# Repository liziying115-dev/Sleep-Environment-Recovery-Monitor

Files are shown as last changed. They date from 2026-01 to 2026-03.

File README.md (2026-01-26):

## Sleep Environment & Recovery Monitor
### Project Overview
#### What it does

The Sleep Environment & Recovery Monitor evaluates overnight sleep conditions — light, sound, temperature — and translates them into a simple, physical recovery score visible in the morning. Instead of tracking the body, the system focuses on environmental quality to encourage healthier sleep habits without medical claims.

#### What it looks like

The system consists of two devices:
* A sensor unit placed on a nightstand that quietly monitors the sleep environment overnight (light, sound, temperature)
* A display unit resembling a small alarm clock with an OLED screen, LED indicator, and a stepper-motor-driven gauge needle that physically points to your sleep quality score

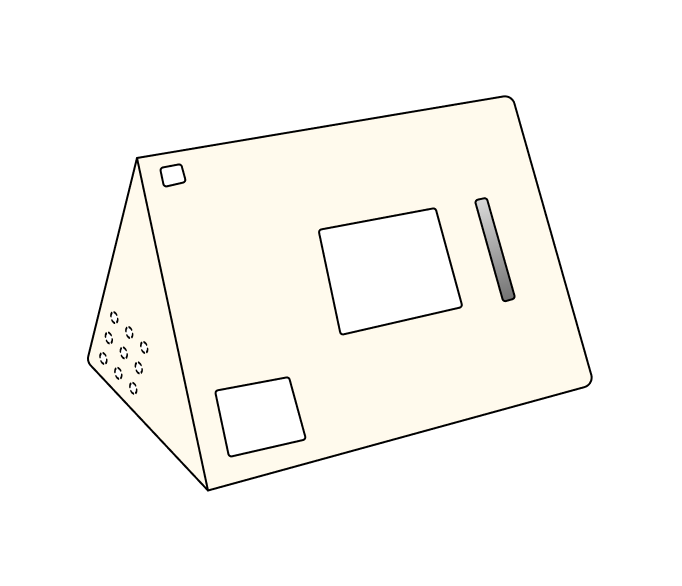
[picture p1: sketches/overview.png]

### Sensor Device (Sleep Environment Monitor)
#### Description
The sensor device continuously monitors environmental conditions during sleep using a low-power duty cycle. Data is aggregated overnight and transmitted wirelessly to the display device in the morning.

#### Sensors & Parts (part numbers)
| Function | Part Number | Quantity | Description |
|---|---|---|---|
| MCU + Wireless| Seeed Studio XIAO ESP32-C3| 1 | BLE, low power |
| Ambient Light Sensor | VEML7700 | 1 | High-sensitivity ambient light sensor (I²C) |
| Microphone | SPH0645LM4H-B | 1 | I²S MEMS microphone, RMS only |
| Temperature | BME280 | 1 | temperature sensing |
| Battery Charger | MCP73831 | 1 | LiPo charging IC |
| LiPo Battery | 3.7V 1000-2000mAh | 1 | Power supply |

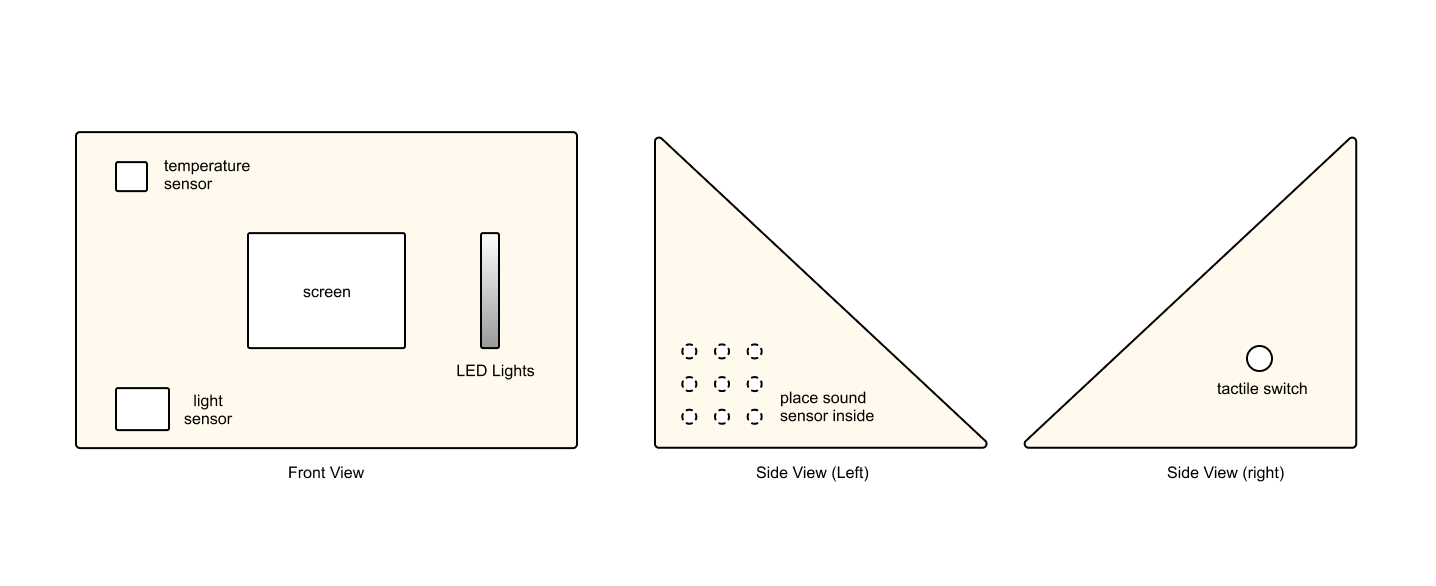
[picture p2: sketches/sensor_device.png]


#### How it works
- The device wakes on a scheduled interval during sleep hours.
- Light, sound RMS, temperature are sampled.
- Audio is processed locally (no recording or storage).
- All data is time-weighted and stored in local memory.
- At wake time, a summary packet is transmitted to the display device.

### Display Device (Score Interface)
#### Description
The display device receives environmental data wirelessly and presents the overnight Sleep Environment Score using multiple feedback channels: a physical gauge needle, OLED screen, and ambient LED indicator. A single button allows the user to cycle through secondary metrics such as light exposure, noise level, and temperature.

#### Components & Parts
| Function | Part Number | Quantity | Notes |
|---|---|---|---|
| MCU + Wireless | Seeed Studio XIAO ESP32-C3 | 1 | Wireless receiver |
| Display | SSD1306 OLED (128×64) | 1 | Low-power I²C screen |
| Stepper Motor | 28BYJ-48 (5V) | 1 | Drives gauge needle |
| Motor Driver  | ULN2003 Driver Board | 1 | Stepper motor driver |
| Gauge Needle  | Custom (3D printed)  | 1 | Physical pointer (0-100) |
| LED | Warm White Diffused LED | 1 | Ambient sleep quality indicator |
| Button | Tactile Momentary Switch | 1 | Metric navigation |
| Battery | LiPo 2000 mAh | 1 | Multi-day operation |
| Resistor | 220Ω | 1 | LED current limiting |

#### Gauge Needle Design

Scale: 0-100 (semi-circular arc)

Zones:
- 0-50: Red zone (Poor)
- 50-70: Orange zone (Fair)
- 70-90: Yellow zone (Good)
- 90-100: Green zone (Excellent)

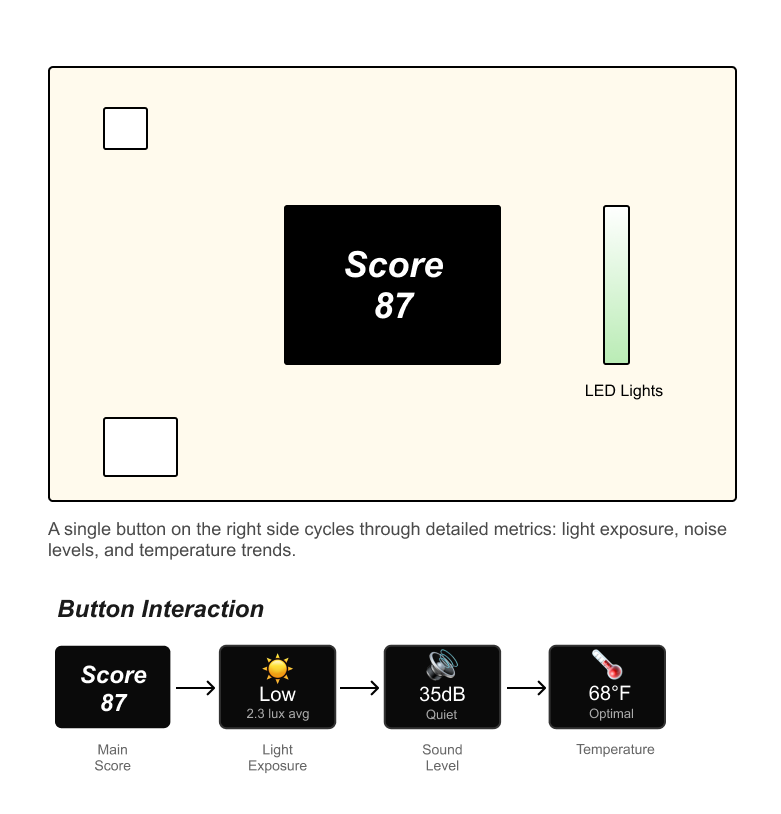
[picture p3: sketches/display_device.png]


### System Communication & Data Flow

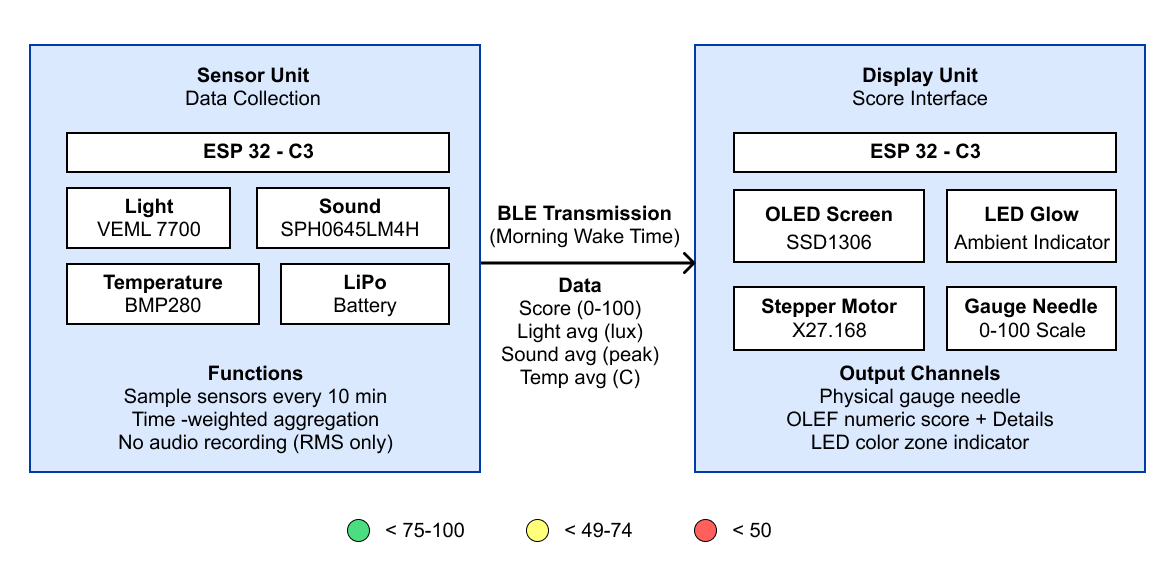
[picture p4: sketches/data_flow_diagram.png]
Data Flow Diagram


*Figure: Complete data pipeline from sensors through processing to display outputs.*

#### System Communication
The system consists of two standalone devices that communicate wirelessly:

Sensor Unit (Transmitter):
- Operates independently overnight
- Collects and aggregates environmental data
- Transmits single summary packet in the morning

Display Unit (Receiver):
- Listens for BLE transmission from sensor unit
- Receives aggregated data and calculated score
- Updates three output channels: gauge needle, OLED, LED

Communication Protocol:
- Technology: BLE
- Pairing: One-time setup, devices remember each other
- Data Format: JSON or binary packet containing:
  - Overall score (0-100)
  - Average light level (lux)
  - Average sound level (dB RMS)
  - Average temperature (°F/°C)
  - Timestamp

#### Data Flow & Processing Pipeline

During Sleep Period:
1. Sensor device periodically samples ambient light, sound level, and temperature
2. Audio data is processed locally using RMS calculation and basic spectral weighting to emphasize disruptive noise patterns
3. All sensor readings are time-weighted (e.g., disruptions during REM sleep weighted higher)
4. Data is aggregated into a single overnight dataset

Morning Transmission:
1. Aggregated data is converted into a normalized Sleep Environment Score (0-100)
2. Score and detailed metrics are packaged into BLE transmission packet
3. Sensor unit broadcasts packet to display unit
4. Display unit receives data and updates all feedback channels

Physical Feedback:
- Gauge Needle: Stepper motor positions needle to corresponding score (0-100 scale)
- OLED Screen: Displays numeric score and allows cycling through detailed metrics
- LED Indicator: Glows with color corresponding to quality zone (green/yellow/orange/red)

### Future Work
- Optional Wi-Fi connectivity to support long-term data logging or remote visualization

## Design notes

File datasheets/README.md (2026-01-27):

## Component Datasheets

This folder contains datasheets for all components used in the Sleep Environment & Recovery Monitor project.

### Sensor Device Components

#### Microcontroller & Wireless
**Seeed Studio XIAO ESP32-C3**
- File: `esp32-c3_datasheet.pdf`
- Description: Low-power MCU with BLE and Wi-Fi capabilities
- Manufacturer: Espressif Systems
- [Product Page](https://wiki.seeedstudio.com/XIAO_ESP32C3_Getting_Started/)

#### Sensors
**VEML7700**
- File: `veml7700_datasheet.pdf`
- Description: High-sensitivity ambient light sensor with I²C interface
- Manufacturer: Vishay Semiconductors
- Interface: I²C
- [Datasheet Link](https://www.vishay.com/docs/84286/veml7700.pdf)

**SPH0645LM4H-B**
- File: `sph0645lm4h_datasheet.pdf`
- Description: I²S MEMS microphone
- Manufacturer: Knowles
- Interface: I²S
- [Datasheet Link](https://www.digikey.com/htmldatasheets/production/1794128/0/0/1/SPH0645LM4H-B-Datasheet.pdf)

**TMP117**
- File: `tmp117_datasheet.pdf`
- Description: High-accuracy digital temperature sensor (±0.1°C)
- Manufacturer: Texas Instruments
- Interface: I²C
- [Datasheet Link](https://www.ti.com/lit/ds/symlink/tmp117.pdf)

OR **BME280**
- File: `bme280_datasheet.pdf`
- Description: digital temperature sensor
- Manufacturer: Bosch Sensortec
- Interface: I²C
- [Datasheet Link](https://www.bosch-sensortec.com/media/boschsensortec/downloads/datasheets/bst-bme280-ds002.pdf)

#### Power Management
**MCP73831**
- File: `mcp73831_datasheet.pdf`
- Description: LiPo battery charging IC
- Manufacturer: Microchip
- [Datasheet Link](https://ww1.microchip.com/downloads/en/DeviceDoc/MCP73831-Family-Data-Sheet-DS20001984H.pdf)

### Display Device Components

#### Display
**SSD1306**
- File: `ssd1306_datasheet.pdf`
- Description: 128×64 OLED display driver with I²C interface
- Manufacturer: Solomon Systech
- Interface: I²C
- [Datasheet Link](https://cdn-shop.adafruit.com/datasheets/SSD1306.pdf)

### Files in This Folder

All component datasheets are stored directly in the `datasheets/` folder:

```
datasheets/
├── README.md
├── esp32-c3_datasheet.pdf
├── veml7700_datasheet.pdf
├── bme280_datasheet.pdf
├── sph0645lm4h_datasheet.pdf
├── tmp117_datasheet.pdf
├── mcp73831_datasheet.pdf
└── ssd1306_datasheet.pdf
```

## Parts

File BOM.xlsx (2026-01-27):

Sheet: Export Summary
This document was exported from Numbers. Each table was converted to an Excel worksheet. All other objects on each Numbers sheet were placed on separate worksheets. Please be aware that formula calculations may differ in Excel.
Numbers Sheet Name | Numbers Table Name | Excel Worksheet Name
Display Unit
 | Table 1 | Display Unit
Sensor Unit
 | Table 1 | Sensor Unit
Component Summary
 | Table 1 | Component Summary
I2C Addresses
 | Table 1 | I2C Addresses

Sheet: Display Unit
Display Unit - Bill of Materials
Item | Qty | Reference | Value/Part Number | Description | Package | Notes | Datasheet
1 | 1 | U1 | XIAO ESP32-C3 | Microcontroller module | Module | Seeed Studio | esp32-c3_datasheet.pdf
3 | 1 | OLED1 | SSD1306 | 0.96" OLED Display 128x64 | I2C Module | Monochrome display | ssd1306_datasheet.pdf
4 | 1 | M1 | Bipolar Stepper | Stepper motor | 4-wire | For gauge needle | -
5 | 1 | D1 | LED | Standard LED (Red/Green/Blue) | 3mm/5mm THT | Status indicator | -
6 | 1 | SW1 | Push Button | Tactile switch | 6x6mm | User button | -
7 | 2 | R1, R2 | 4.7kΩ | Pull-up resistor | 0805/THT 1/4W | I2C bus (SDA, SCL) | -
8 | 1 | R3 | 220Ω | Current limiting resistor | 0805/THT 1/4W | LED protection | -
9 | 1 | C1 | 100µF | Electrolytic capacitor | Radial | Motor power decoupling | -
10 | 1 | C2 | 100nF | Ceramic capacitor | 0805 | OLED power decoupling | -
Power Requirements:
Voltage: 3.3-5V USB
Current (typical): ~200mA
Current (peak): ~500mA (motor active)

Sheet: Sensor Unit
Sensor Unit - Bill of Materials
Item | Qty | Reference | Value/Part Number | Description | Package | Notes | Datasheet
1 | 1 | U4 | XIAO ESP32-C3 | Microcontroller module | Module | Seeed Studio | esp32-c3_datasheet.pdf
2 | 1 | U5 | BME280 | Temp/Humidity/Pressure sensor | LGA-8 (2.5x2.5mm) | I2C interface | bme280_datasheet.pdf
3 | 1 | U6 | VEML7700 | Ambient light sensor | OPLGA-4 | I2C address: 0x10 | veml7700_datasheet.pdf
4 | 1 | MK1 | SPH0645LM4H-B | MEMS microphone | Module | I2S digital output | sph0645lm4h_datasheet.pdf
5 | 2 | R1, R2 | 4.7kΩ | Pull-up resistor | 0805/THT 1/4W | I2C bus (SDA, SCL) | -
6 | 3 | C1-C3 | 100nF | Ceramic capacitor | 0805 | Sensor power decoupling | -
7 | 1 | BAT1 | 18650 Li-ion | Battery | - | 3.7V, 2500mAh | -
Power Requirements:
Voltage: 5V USB / 3.7V Battery
Current (typical): ~50mA
Current (peak): ~100mA

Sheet: Component Summary
Passive Components Summary
Component | Display Unit | Sensor Unit | Total
4.7kΩ resistor | 2 | 2 | 4
220Ω resistor | 1 | 0 | 1
100µF capacitor | 1 | 0 | 1
100nF capacitor | 1 | 3 | 4

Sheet: I2C Addresses
I2C Device Address Map
Device | Address | Bus/Unit
SSD1306 OLED | 0x3C | Display Unit
VEML7700 | 0x10 | Sensor Unit
BME280 | 0x76 (SDO=GND) | Sensor Unit

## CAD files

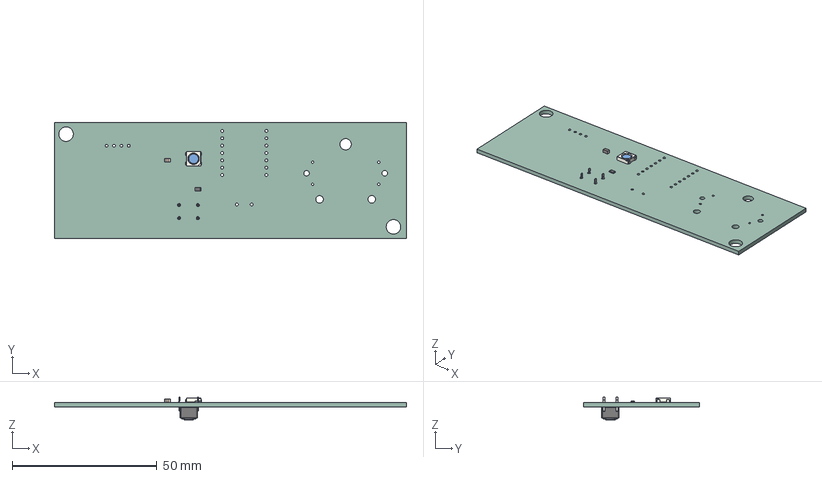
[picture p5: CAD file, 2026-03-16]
schematics_Display/Display Unit.step
121.5 x 40.0 x 7.80 mm
LED_WS2812B_PLCC4_5.0x5.0mm_P3.2mm
R_0805_2012Metric
C_0805_2012Metric
SW_PUSH_6mm_H4.3mm
Display Unit_PCB

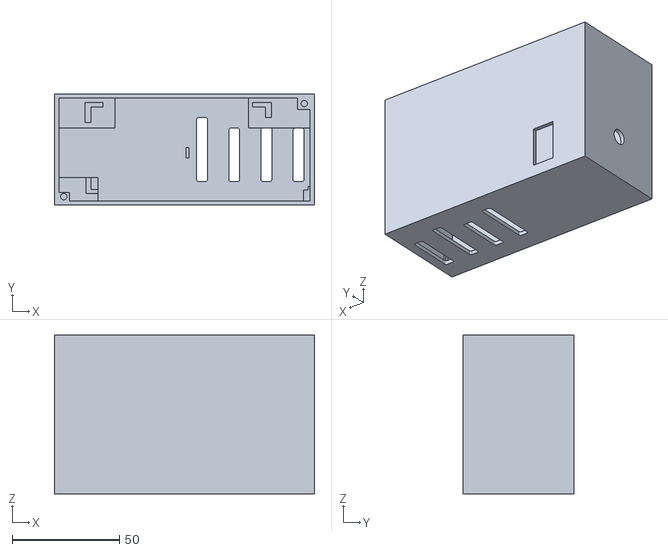
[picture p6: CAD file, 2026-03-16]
schematics_sensor/Sensor_Unit_Print_b.stl
121.3 x 52.0 x 74.0

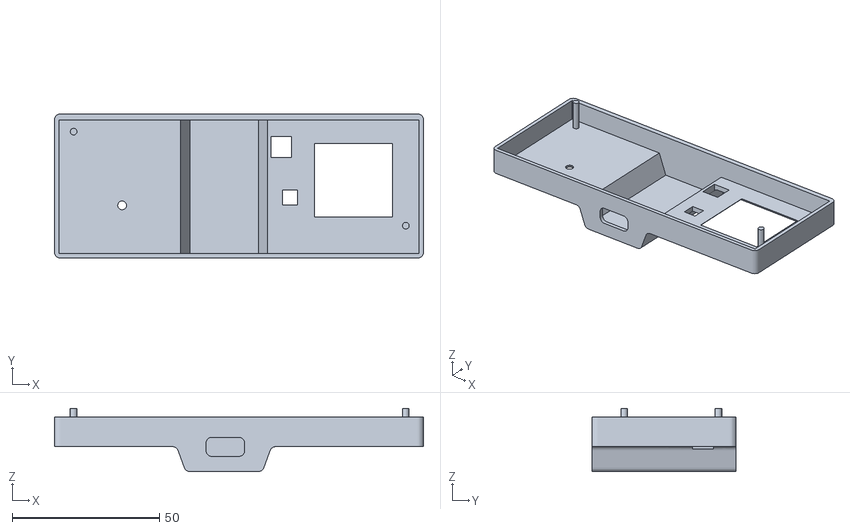
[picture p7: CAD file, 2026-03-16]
schematics_Display/Display Unit_Print_top2.stl
125.5 x 49.0 x 21.5

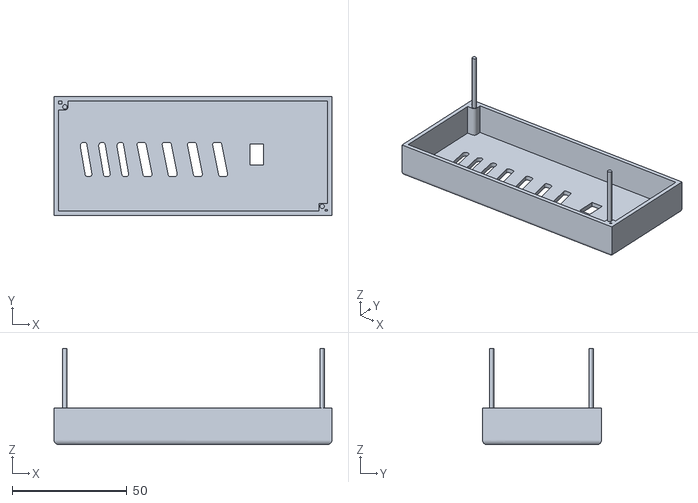
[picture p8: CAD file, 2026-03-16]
schematics_sensor/Sensor_Unit_Print_top2.stl
121.3 x 52.0 x 42.0

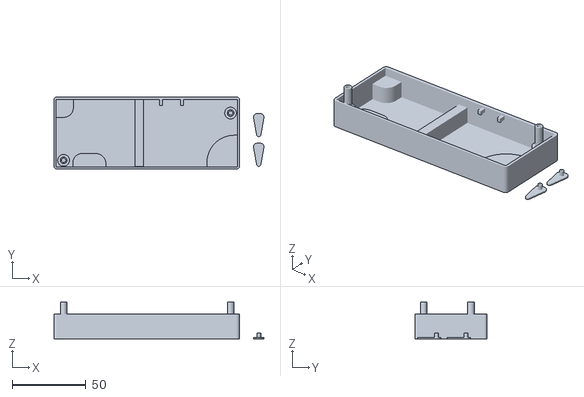
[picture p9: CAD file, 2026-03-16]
schematics_Display/Display Unit_Print_b2.stl
142.1 x 49.0 x 25.0

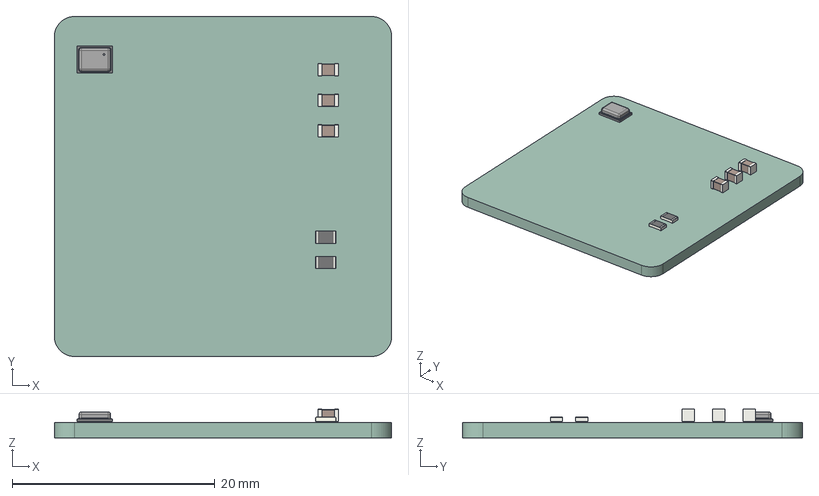
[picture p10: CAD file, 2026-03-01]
schematics_sensor/sensor_unit.step
33.2 x 33.5 x 2.84 mm
Knowles_SPH0645LM4H-6_3.5x2.65mm
R_0805_2012Metric x 2
C_0805_2012Metric x 3
sensor_unit_PCB

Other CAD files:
schematics_sensor/sensor_unit.stl

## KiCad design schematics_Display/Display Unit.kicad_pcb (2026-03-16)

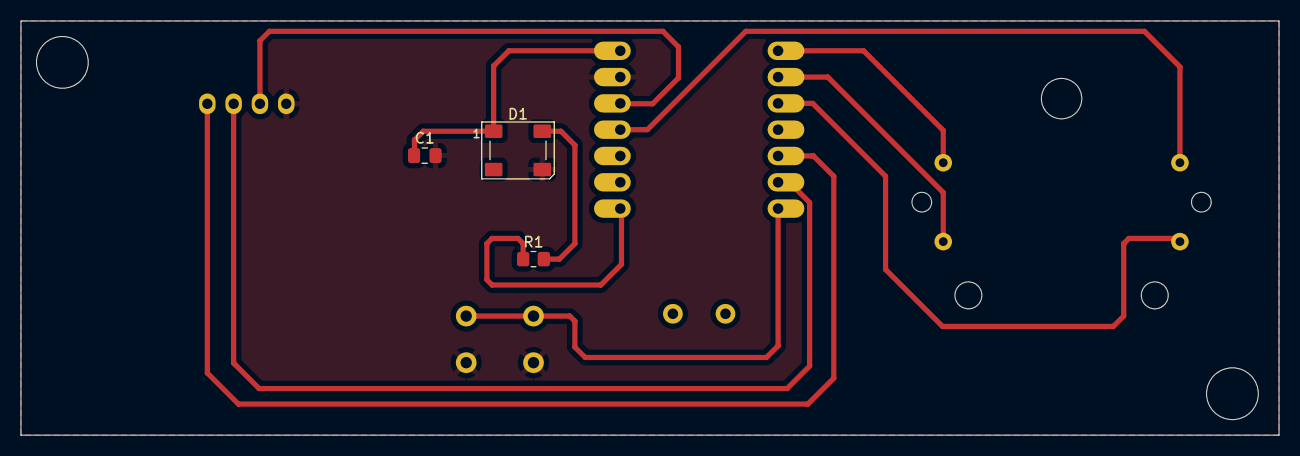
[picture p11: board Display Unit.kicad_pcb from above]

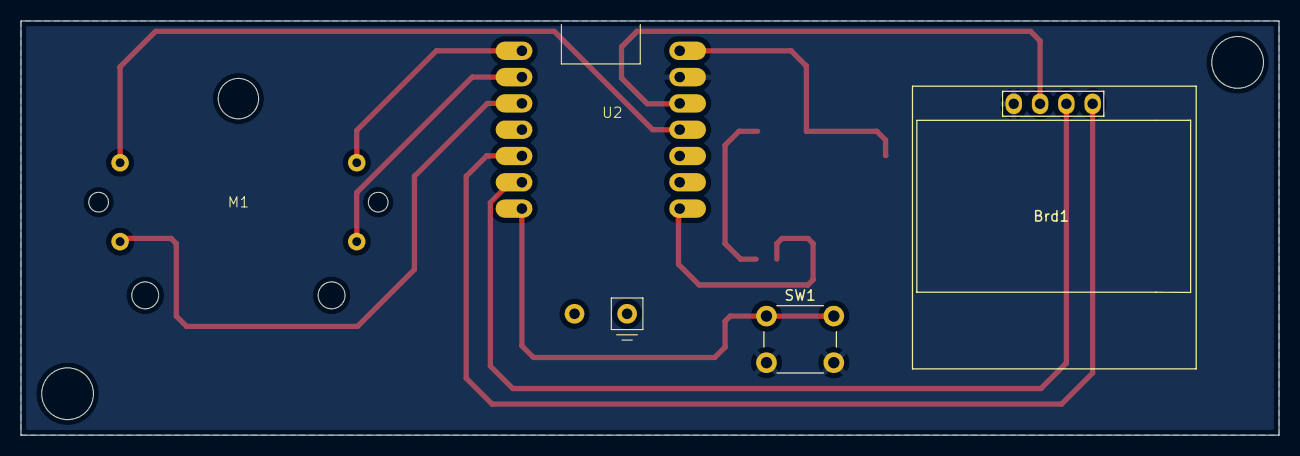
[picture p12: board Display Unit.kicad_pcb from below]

Board: 2 copper layers, 121.5 x 40.0 mm, 7 parts (4 on the bottom side), 12 nets.

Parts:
Brd1: SSD1306; 128x64OLED
C1: 100nF; C_0805_2012Metric_Pad1.18x1.45mm_HandSolder
D1: WS2812B; LED_WS2812B_PLCC4_5.0x5.0mm_P3.2mm
M1: Stepper_Motor_bipolar; x27_stepper_two_holes
R1: 33Ω; R_0805_2012Metric_Pad1.20x1.40mm_HandSolder
SW1: SW_Push; SW_PUSH_6mm_H4.3mm
U2: XIAO_ESP32C3; XIAO_ESP32

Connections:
GND: Brd1.1 (GND), C1.2, D1.3 (VSS), SW1.2, U2.13 (GND)
unnamed: Brd1.3 (SCL), U2.6 (GPIO6_A5_D5_SCL)
unnamed: Brd1.4 (SDA), U2.5 (GPIO4_A3_D3_SDA)
unnamed: Brd1.2 (VCC), U2.12 (3V3)
unnamed: D1.4 (DIN), R1.2
unnamed: C1.1, D1.1 (VDD), U2.14 (5V)
unnamed: M1.2 (-), U2.2 (GPIO2_A1_D1)
unnamed: M1.1, U2.1 (GPIO1_A0_D0)
unnamed: M1.4, U2.3 (GPIO3_A2_D2)
unnamed: M1.3, U2.11 (GPIO9_A10_D10_COPI)
unnamed: SW1.1, U2.7 (GPIO43_TX_D6)
unnamed: R1.1, U2.8 (GPIO44_D7_RX)

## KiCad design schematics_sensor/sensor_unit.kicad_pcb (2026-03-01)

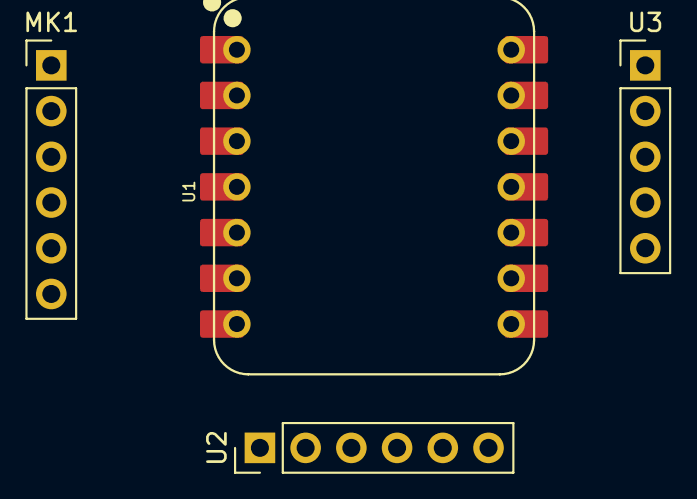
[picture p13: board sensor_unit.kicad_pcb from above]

Board: 2 copper layers, 4 parts (0 on the bottom side), 7 nets, no tracks yet.

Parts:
MK1: SPH0645LM4H; PinHeader_1x06_P2.54mm_Vertical
U1: XIAO ESP32C3; XIAO-ESP32-C3-DIP
U2: BMP280; PinHeader_1x06_P2.54mm_Vertical
U3: VEML7700; PinHeader_1x05_P2.54mm_Vertical

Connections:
unnamed: MK1.5 (3V), U1.12 (3V3), U2.2 (CSB), U2.6 (VDDIO), U3.1 (VIN)
unnamed: MK1.4 (BCLK), U1.2 (GPIO2_A1_D1)
unnamed: MK1.6 (DOUT), U1.3 (GPIO3_A2_D2)
unnamed: MK1.2 (SEL), MK1.3 (GND), U1.13 (GND), U2.1 (GND), U2.5 (SDO), U3.3 (GND)
unnamed: MK1.1 (LRCL), U1.1 (GPIO1_A0_D0)
unnamed: U1.5 (GPIO4_A3_D3_SDA), U2.3 (SDI), U3.5 (SDA)
unnamed: U1.6 (GPIO6_A5_D5_SCL), U2.4 (SCK), U3.4 (SCL)

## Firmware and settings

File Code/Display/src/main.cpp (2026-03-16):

#include <Arduino.h>
#include <Wire.h>
#include <Adafruit_SSD1306.h>
#include <Adafruit_NeoPixel.h>
#include <BLEDevice.h>
#include <BLEScan.h>
#include <BLEAdvertisedDevice.h>

// ─── NeoPixel ─────────────────────────────────────────────────────────────────
#define NEOPIXEL_PIN  D7   // change to whichever pin your NeoPixel data line is on
#define NEOPIXEL_NUM  1
Adafruit_NeoPixel pixel(NEOPIXEL_NUM, NEOPIXEL_PIN, NEO_GRB + NEO_KHZ800);

// ─── OLED ─────────────────────────────────────────────────────────────────────
#define SCREEN_WIDTH  128
#define SCREEN_HEIGHT  64
#define OLED_RESET     -1
Adafruit_SSD1306 display(SCREEN_WIDTH, SCREEN_HEIGHT, &Wire, OLED_RESET);

// ─── Stepper motor ────────────────────────────────────────────────────────────
#define MOTOR_PIN1  10
#define MOTOR_PIN2   4
#define MOTOR_PIN3   3
#define MOTOR_PIN4   2
#define STEP_DELAY_MS 8

const int motorSeq[4][4] = {
  {1, 0, 1, 0},
  {0, 1, 1, 0},
  {0, 1, 0, 1},
  {1, 0, 0, 1}
};

int currentStep     = 0;
int currentPosition = 0;   // absolute step count from home

void stepMotor(int s) {
  digitalWrite(MOTOR_PIN1, motorSeq[s][0]);
  digitalWrite(MOTOR_PIN2, motorSeq[s][1]);
  digitalWrite(MOTOR_PIN3, motorSeq[s][2]);
  digitalWrite(MOTOR_PIN4, motorSeq[s][3]);
}

void motorOff() {
  // De-energise all coils to save power / heat
  digitalWrite(MOTOR_PIN1, LOW);
  digitalWrite(MOTOR_PIN2, LOW);
  digitalWrite(MOTOR_PIN3, LOW);
  digitalWrite(MOTOR_PIN4, LOW);
}

// ─── NeoPixel color ───────────────────────────────────────────────────────────
void setLedForScore(uint8_t score) {
  if (score >= 75) {
    pixel.setPixelColor(0, pixel.Color(0, 180, 0));   // 好 → green
  } else if (score >= 50) {
    pixel.setPixelColor(0, pixel.Color(180, 100, 0)); // 中 → yellow
  } else {
    pixel.setPixelColor(0, pixel.Color(180, 0, 0));   // 差 → red
  }
  pixel.show();
}

void moveToPosition(int target) {
  int steps = target - currentPosition;
  int dir   = (steps > 0) ? 1 : -1;
  steps     = abs(steps);
  for (int i = 0; i < steps; i++) {
    currentStep     = (currentStep + dir + 4) % 4;
    currentPosition += dir;
    stepMotor(currentStep);
    delay(STEP_DELAY_MS);
  }
  motorOff();
}

void homeMotor() {
  currentPosition = 0;
  Serial.println("[Motor] Position reset to 0 (manual home assumed).");
}

#define MAX_STEPS 430

int scoreToPosition(uint8_t score) {
  return -(int)((score / 100.0f) * MAX_STEPS);
}

const char* scoreLabel(uint8_t score) {
  if (score >= 75) return "GOOD";
  if (score >= 50) return "OK";
  return "POOR";
}

// ─── Button ───────────────────────────────────────────────────────────────────
#define BUTTON_PIN 21

bool buttonPressed() {
  if (digitalRead(BUTTON_PIN) == LOW) {
    delay(50);  // debounce
    if (digitalRead(BUTTON_PIN) == LOW) {
      while (digitalRead(BUTTON_PIN) == LOW);  // wait for release
      return true;
    }
  }
  return false;
}

// ─── OLED centered text helpers ───────────────────────────────────────────────
void printCentered(const char* text, int y, int textSize = 1) {
  display.setTextSize(textSize);
  int16_t x1, y1;
  uint16_t w, h;
  display.getTextBounds(text, 0, y, &x1, &y1, &w, &h);
  int x = (SCREEN_WIDTH - w) / 2;
  display.setCursor(x, y);
  display.print(text);
}

// ─── Screen definitions ───────────────────────────────────────────────────────

void oledStatus(const char* line1, const char* line2 = nullptr) {
  display.clearDisplay();
  display.setTextColor(SSD1306_WHITE);
  printCentered(line1, line2 ? 20 : 28, 1);
  if (line2) printCentered(line2, 38, 1);
  display.display();
}

// Screen 0: main score
void showScreenScore(uint8_t score) {
  display.clearDisplay();
  display.setTextColor(SSD1306_WHITE);

  // Score label e.g. "Score"
  printCentered("Score", 6, 1);

  // Large number
  char buf[8];
  snprintf(buf, sizeof(buf), "%d", score);
  printCentered(buf, 18, 3);

  // Rating label
  printCentered(scoreLabel(score), 52, 1);

  display.display();
}

// Screen 1: light
void showScreenLight(float lux) {
  display.clearDisplay();
  display.setTextColor(SSD1306_WHITE);

  printCentered("Light", 12, 2);

  char buf[16];
  snprintf(buf, sizeof(buf), "%.0f lux", lux);
  printCentered(buf, 38, 1);

  display.display();
}

// Screen 2: temperature
void showScreenTemp(float temp) {
  display.clearDisplay();
  display.setTextColor(SSD1306_WHITE);

  printCentered("Temperature", 12, 1);

  char buf[16];
  snprintf(buf, sizeof(buf), "%.1f C", temp);
  printCentered(buf, 30, 2);

  display.display();
}

// Screen 3: sound
void showScreenSound(float snd) {
  display.clearDisplay();
  display.setTextColor(SSD1306_WHITE);

  printCentered("Sound", 12, 2);

  char buf[16];
  snprintf(buf, sizeof(buf), "%.0f peak", snd);
  printCentered(buf, 38, 1);

  display.display();
}

// Screen 4: goodnight
void showScreenGoodnight() {
  display.clearDisplay();
  display.setTextColor(SSD1306_WHITE);

  printCentered("Have A", 10, 2);
  printCentered("Good Night", 30, 2);

  display.display();
}

// ─── BLE scan ─────────────────────────────────────────────────────────────────
struct SleepData {
  bool    received = false;
  uint8_t score    = 0;
  float   lux      = 0;
  float   sound    = 0;
  float   temp     = 0;
};

SleepData gData;

class SleepCallback : public BLEAdvertisedDeviceCallbacks {
  void onResult(BLEAdvertisedDevice dev) override {
    if (!dev.haveName() || dev.getName() != "SlpSns") return;
    if (!dev.haveManufacturerData()) return;

    std::string mfr = dev.getManufacturerData();
    // Strip 2-byte company ID prefix, rest is CSV string
    if (mfr.size() < 3) return;
    std::string csv = mfr.substr(2);

    Serial.printf("[BLE] Raw CSV: [%s]\n", csv.c_str());

    // Parse "score,lux,snd,temp"
    float parsedScore, parsedLux, parsedSnd, parsedTemp;
    int matched = sscanf(csv.c_str(), "%f,%f,%f,%f",
                         &parsedScore, &parsedLux, &parsedSnd, &parsedTemp);
    if (matched != 4) {
      Serial.printf("[BLE] Parse failed, matched=%d\n", matched);
      return;
    }

    gData.score    = (uint8_t)constrain((int)parsedScore, 0, 100);
    gData.lux      = parsedLux;
    gData.sound    = parsedSnd * 100.0f;   // was divided by 100 on sensor side
    gData.temp     = parsedTemp;
    gData.received = true;

    Serial.printf("[BLE] Parsed: score=%d lux=%.1f snd=%.0f temp=%.1f\n",
                  gData.score, gData.lux, gData.sound, gData.temp);

    BLEDevice::getScan()->stop();
  }
};

// ─── setup / loop ─────────────────────────────────────────────────────────────
void setup() {
  Serial.begin(115200);
  delay(1000);
  Serial.println("=== Display Unit (Demo Mode) ===");

  // NeoPixel init
  pixel.begin();
  pixel.setBrightness(80);  // 0–255, keep moderate for classroom
  pixel.clear();
  pixel.show();

  // Button init
  pinMode(BUTTON_PIN, INPUT_PULLUP);

  // Motor init
  pinMode(MOTOR_PIN1, OUTPUT);
  pinMode(MOTOR_PIN2, OUTPUT);
  pinMode(MOTOR_PIN3, OUTPUT);
  pinMode(MOTOR_PIN4, OUTPUT);

  // OLED init
  Wire.begin(D4, D5);
  if (!display.begin(SSD1306_SWITCHCAPVCC, 0x3C)) {
    Serial.println("[ERROR] SSD1306 not found!");
    while (true);
  }
  oledStatus("Set pointer to", "POOR position!");
  delay(3000);   // 给你3秒时间手动拨指针
  homeMotor();
  oledStatus("Scanning BLE...", "Waiting for sensor");

  // BLE init
  BLEDevice::init("SleepDisplay");
  Serial.println("[OK] BLE ready — scanning for SleepSensor");
}

// ─── State ────────────────────────────────────────────────────────────────────
bool motorMoved  = false;
int  screenIndex = 0;   // 0=Score 1=Light 2=Temp 3=Sound 4=Goodnight

void showCurrentScreen() {
  switch (screenIndex) {
    case 0: showScreenScore(gData.score);   break;
    case 1: showScreenLight(gData.lux);     break;
    case 2: showScreenTemp(gData.temp);     break;
    case 3: showScreenSound(gData.sound);   break;
    case 4: showScreenGoodnight();          break;
    default: showScreenGoodnight();         break;
  }
}

void resetAll() {
  gData.received  = false;
  gData.score     = 0;
  gData.lux       = 0;
  gData.sound     = 0;
  gData.temp      = 0;
  motorMoved      = false;
  screenIndex     = 0;

  // Return motor to home position
  moveToPosition(0);

  // Turn off LED
  pixel.clear();
  pixel.show();

  Serial.println("[Reset] Ready for next scan.");
}

void loop() {
  // ── Phase 1: waiting for BLE data ─────────────────────────────────────────
  if (!gData.received) {
    oledStatus("Scanning BLE...", "Waiting for sensor");
    BLEScan* scan = BLEDevice::getScan();
    scan->setAdvertisedDeviceCallbacks(new SleepCallback(), true);
    scan->setActiveScan(true);
    scan->setInterval(100);
    scan->setWindow(99);
    scan->start(5, false);
    scan->clearResults();
    return;
  }

  // ── Phase 2: first time data arrives — move motor + show score ────────────
  if (!motorMoved) {
    setLedForScore(gData.score);

    int target = scoreToPosition(gData.score);
    Serial.printf("[Motor] Moving to position %d (score=%d)\n", target, gData.score);
    moveToPosition(target);

    screenIndex = 0;
    showCurrentScreen();
    motorMoved = true;
    Serial.println("[Done] Score displayed. Press button to cycle metrics.");
    return;
  }

  // ── Phase 3: button cycles through screens ────────────────────────────────
  if (buttonPressed()) {
    if (screenIndex < 4) {
      screenIndex++;
      showCurrentScreen();
      Serial.printf("[Button] Screen %d\n", screenIndex);
    } else {
      // On goodnight screen — reset and start over
      resetAll();
    }
  }

  delay(20);
}

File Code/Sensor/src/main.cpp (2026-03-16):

#include <Arduino.h>
#include <Wire.h>
#include <math.h>
#include <Adafruit_VEML7700.h>
#include <Adafruit_BMP280.h>
#include <driver/i2s.h>
#include <BLEDevice.h>
#include <BLEAdvertising.h>

// ─── Pin definitions ──────────────────────────────────────────────────────────
#define STATUS_LED  D6
#define I2S_BCLK    D0
#define I2S_LRCK    D1
#define I2S_DOUT    D2

// ─── Demo config ──────────────────────────────────────────────────────────────
#define NUM_READINGS   5
#define READING_DELAY  5000   // ms between readings

// ─── BLE config ───────────────────────────────────────────────────────────────
#define SLEEP_SERVICE_UUID  "12345678-1234-1234-1234-123456789012"

// ─── Sensor objects ───────────────────────────────────────────────────────────
Adafruit_VEML7700 veml;
Adafruit_BMP280   bmp;
bool vemlOK = false;
bool bmpOK  = false;

// ─── I2S setup for SPH0645 ────────────────────────────────────────────────────
void setupI2S() {
  i2s_config_t cfg = {
    .mode               = (i2s_mode_t)(I2S_MODE_MASTER | I2S_MODE_RX),
    .sample_rate        = 16000,
    .bits_per_sample    = I2S_BITS_PER_SAMPLE_32BIT,
    .channel_format     = I2S_CHANNEL_FMT_ONLY_LEFT,
    .communication_format = I2S_COMM_FORMAT_STAND_I2S,
    .intr_alloc_flags   = ESP_INTR_FLAG_LEVEL1,
    .dma_buf_count      = 4,
    .dma_buf_len        = 256,
    .use_apll           = false,
    .tx_desc_auto_clear = false,
    .fixed_mclk         = 0
  };
  i2s_pin_config_t pins = {
    .bck_io_num    = D0,
    .ws_io_num     = D1,
    .data_out_num  = I2S_PIN_NO_CHANGE,
    .data_in_num   = D2
  };
  i2s_driver_install(I2S_NUM_0, &cfg, 0, NULL);
  i2s_set_pin(I2S_NUM_0, &pins);
}

int noiseFloor = 0;   // measured at startup

void calibrateNoiseFloor() {
  Serial.println("[Mic] Calibrating noise floor...");
  // Discard first few frames to let mic stabilize
  int32_t discard[256];
  size_t dummy;
  for (int i = 0; i < 5; i++) {
    i2s_read(I2S_NUM_0, discard, sizeof(discard), &dummy, 100);
  }
  // Measure baseline over 3 readings
  long sum = 0;
  for (int r = 0; r < 3; r++) {
    int32_t samples[256];
    size_t bytes_read;
    i2s_read(I2S_NUM_0, samples, sizeof(samples), &bytes_read, 100);
    int count = bytes_read / sizeof(int32_t);
    double sumSq = 0;
    for (int i = 0; i < count; i++) {
      double val = (double)(samples[i] >> 14);
      sumSq += val * val;
    }
    sum += (int)sqrt(sumSq / count);
  }
  noiseFloor = sum / 3;
  Serial.printf("[Mic] Noise floor = %d\n", noiseFloor);
}

int readMicLevel() {
  int32_t samples[256];
  size_t  bytes_read;
  i2s_read(I2S_NUM_0, samples, sizeof(samples), &bytes_read, 100);

  int count = bytes_read / sizeof(int32_t);
  if (count == 0) return 0;

  double sumSquares = 0;
  for (int i = 0; i < count; i++) {
    double val = (double)(samples[i] >> 14);
    sumSquares += val * val;
  }
  int rms = (int)sqrt(sumSquares / count);

  // Subtract noise floor, clamp to 0
  return max(0, rms - noiseFloor);
}

// ─── Threshold Classifier ────────────────────────────────────────────────────

typedef enum { LVL_POOR = 0, LVL_OK = 1, LVL_GOOD = 2 } SensorLevel;

SensorLevel classifyLight(float lux) {
  if (lux < 5.0f)  return LVL_GOOD;
  if (lux < 20.0f) return LVL_OK;
  return LVL_POOR;
}

SensorLevel classifySound(float peak) {
  if (peak < 500)  return LVL_GOOD;   // quiet after noise floor removed
  if (peak < 2000) return LVL_OK;     // moderate
  return LVL_POOR;                     // loud
}

SensorLevel classifyTemp(float temp) {
  if (temp >= 18.0f && temp <= 22.0f) return LVL_GOOD;
  if (temp >= 15.0f && temp <= 25.0f) return LVL_OK;
  return LVL_POOR;
}

const char* levelName(SensorLevel l) {
  if (l == LVL_GOOD) return "GOOD";
  if (l == LVL_OK)   return "OK";
  return "POOR";
}

// Convert classified levels → final score (0–100)
// Weights: Light 40%, Sound 40%, Temperature 20%
int calcScore(float avgLux, float avgSound, float avgTemp) {
  SensorLevel lightLevel = classifyLight(avgLux);
  SensorLevel soundLevel = classifySound(avgSound);
  SensorLevel tempLevel  = classifyTemp(avgTemp);

  Serial.printf("  Light class:  %s\n", levelName(lightLevel));
  Serial.printf("  Sound class:  %s\n", levelName(soundLevel));
  Serial.printf("  Temp  class:  %s\n", levelName(tempLevel));

  // Each level maps to a score fraction: POOR=0, OK=0.5, GOOD=1.0
  float lightScore = (lightLevel / 2.0f) * 40.0f;
  float soundScore = (soundLevel / 2.0f) * 40.0f;
  float tempScore  = (tempLevel  / 2.0f) * 20.0f;

  int total = (int)(lightScore + soundScore + tempScore);
  return constrain(total, 0, 100);
}

// ─── BLE broadcast ────────────────────────────────────────────────────────────

void broadcastScore(uint8_t score, float lux, float snd, float temp) {
  BLEDevice::init("SleepSensor");

  // Keep payload short to fit BLE 31-byte advertisement limit.
  // Format: "score,lux,snd,temp" with reduced precision
  // e.g. "46,17,139,20" (sound divided by 100, reconstructed on display)
  char payload[24];
  snprintf(payload, sizeof(payload), "%d,%d,%d,%d",
           (int)score,
           (int)lux,
           (int)(snd / 100),   // divide by 100 to keep short; display multiplies back
           (int)temp);

  std::string mfr;
  mfr += (char)0xFF;
  mfr += (char)0xFF;
  mfr += std::string(payload);

  BLEAdvertisementData advData;
  advData.setName("SlpSns");   // shorter name saves bytes
  advData.setManufacturerData(mfr);

  BLEAdvertising* adv = BLEDevice::getAdvertising();
  adv->setAdvertisementData(advData);
  adv->start();

  Serial.printf("\n>>> BLE broadcasting payload: [%s]\n", payload);
}

// ─── setup / loop ─────────────────────────────────────────────────────────────
void setup() {
  Serial.begin(115200);
  delay(1000);
  Serial.println("=== Sensor Unit (Demo Mode) ===");

  // Status LED on during init
  pinMode(STATUS_LED, OUTPUT);
  digitalWrite(STATUS_LED, HIGH);
  delay(2000);
  digitalWrite(STATUS_LED, LOW);

  Wire.begin(D4, D5);
  delay(100);

  if (!veml.begin(&Wire)) {
    Serial.println("[WARN] VEML7700 not found");
  } else {
    Serial.println("[OK]  VEML7700 ready");
    vemlOK = true;
  }

  if (!bmp.begin(0x76)) {
    Serial.println("[WARN] BMP280 not found");
  } else {
    Serial.println("[OK]  BMP280 ready");
    bmpOK = true;
    bmp.setSampling(Adafruit_BMP280::MODE_NORMAL,
                    Adafruit_BMP280::SAMPLING_X2,
                    Adafruit_BMP280::SAMPLING_X16,
                    Adafruit_BMP280::FILTER_X16,
                    Adafruit_BMP280::STANDBY_MS_500);
  }

  setupI2S();
  calibrateNoiseFloor();
  Serial.println("[OK]  SPH0645 ready");
  Serial.printf("\nStarting %d readings, %d s apart...\n\n", NUM_READINGS, READING_DELAY / 1000);
}

bool done = false;
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

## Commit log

2026-01-19 add README with data flow diagram and corrections
2026-01-20 Add detailed device sketches
2026-01-25 Add stepper motor gauge needle and update system architecture
2026-01-27 add schematics
    [Untitled.kicad_pcb, electrical_schematics.kicad_sch]
2026-01-27 add bom
    [BOM_Complete.xlsx]
2026-02-08 Power model
    [BOM.xlsx, Display Unit.kicad_sch, Untitled.kicad_pcb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]
2026-03-01 Add sensor unit test coed
    [Display Unit.kicad_pcb, Display Unit.kicad_sch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]
2026-03-16 add coding, pcb, and revised sketches
    [Display Unit.kicad_pcb, Display Unit.kicad_sch, Display Unit.step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]
